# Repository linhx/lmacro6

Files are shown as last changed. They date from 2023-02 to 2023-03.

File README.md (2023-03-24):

# LMACRO6

My custom macropad

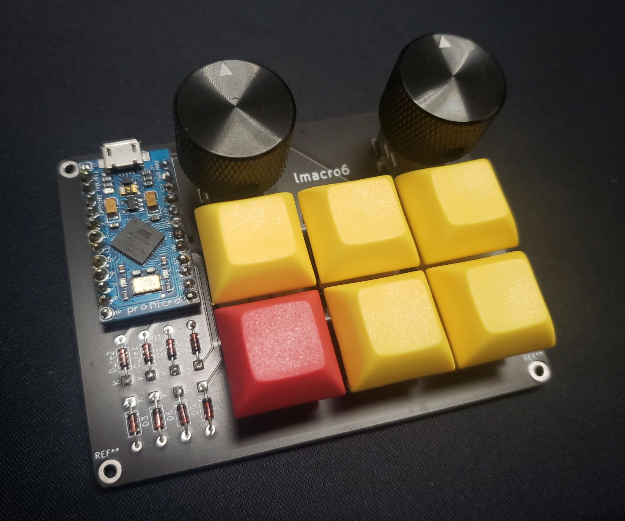
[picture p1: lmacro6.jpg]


## Default keymap

```plaintext
| F20            |            | Mute        |
| Ctrl + F12     | Alt + Left | Alt + Right |
| Ctrl + Alt + T |            |             |

* Left rotary encoder: Switch layer
* Right rotary encoder: Volume up/down

```

### useful macros (config via VIA)

* Open terminal in a directory (Nautilus Ubuntu): {KC_F10}{500}{KC_LALT,KC_E}

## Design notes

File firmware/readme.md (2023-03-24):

# lmacro6

A simple 6-keys macropad with two rotary encoders.

* Keyboard Maintainer: [Linhx](https://github.com/linhx)
* Hardware Supported: atmega32u4
* Hardware Availability: https://github.com/linhx/lmacro6

See the [build environment setup](https://docs.qmk.fm/#/getting_started_build_tools) and the [make instructions](https://docs.qmk.fm/#/getting_started_make_guide) for more information. Brand new to QMK? Start with our [Complete Newbs Guide](https://docs.qmk.fm/#/newbs).

## Default layout

```plaintext
| F20            |            | Mute        |
| Ctrl + F12     | Alt + Left | Alt + Right |
| Ctrl + Alt + T |            |             |

* Left rotary encoder: Switch layer
* Right rotary encoder: Volume up/down
```

### useful macros (config via VIA)

* Open terminal in a directory (Nautilus Ubuntu): {KC_F10}{500}{KC_LALT,KC_E}

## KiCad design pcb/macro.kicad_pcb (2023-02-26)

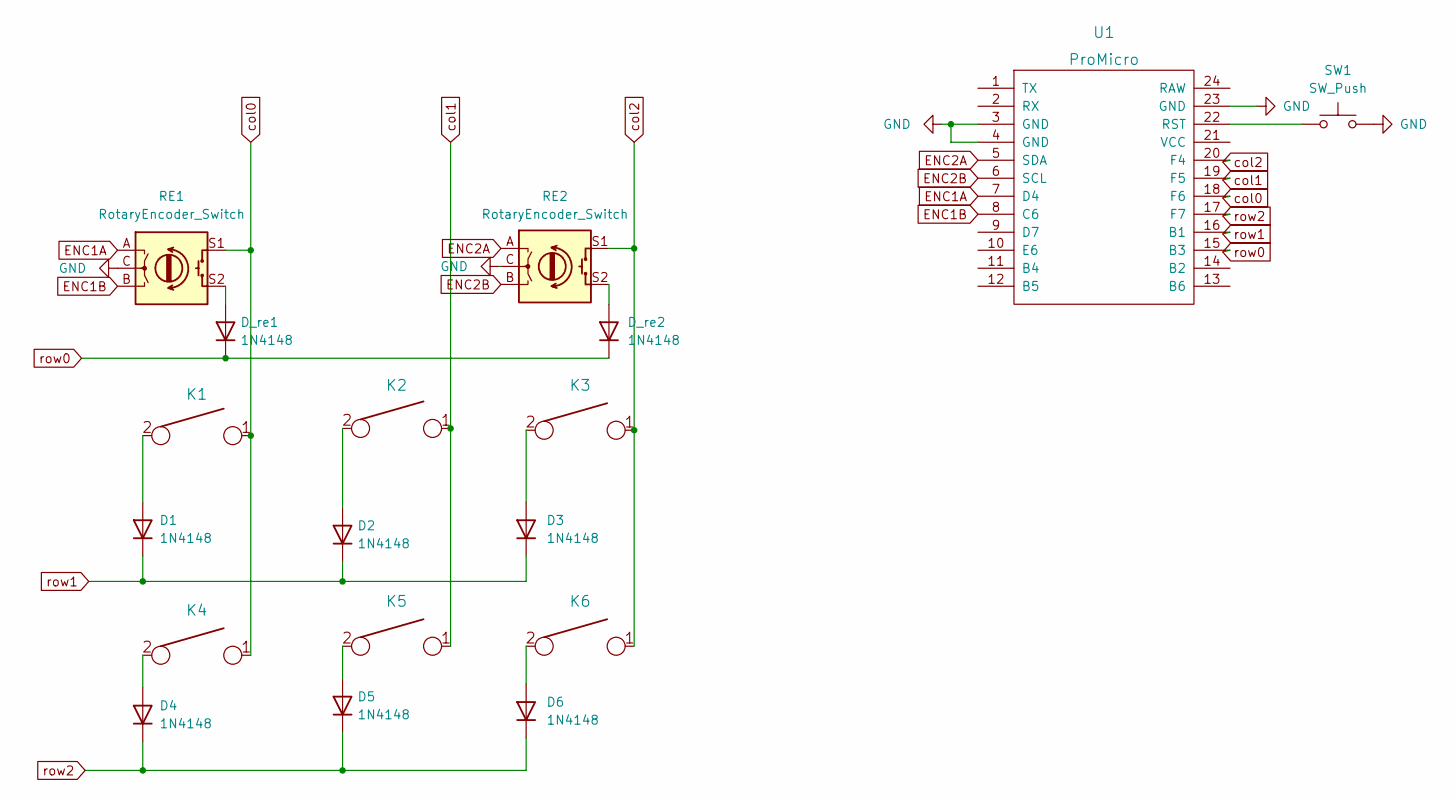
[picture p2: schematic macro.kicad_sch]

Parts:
D1, D2, D3, D4, D5, D6: 1N4148; D_DO-35_SOD27_P7.62mm_Horizontal
D_re1, D_re2: 1N4148; D_DO-35_SOD27_P7.62mm_Horizontal
K1, K2, K3, K4, K5, K6: KEYSW; SW_Cherry_MX_PCB_1.00u
RE1, RE2: RotaryEncoder_Switch; RotaryEncoder_Alps_EC11E-Switch_Vertical_H20mm
SW1: SW_Push; SW_SPST_CK_RS282G05A3
U1: ProMicro; Sparkfun_Pro_Micro

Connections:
ENC1A: RE1.A, U1.7 (D4)
ENC1B: RE1.B, U1.8 (C6)
ENC2A: RE2.A, U1.5 (SDA)
ENC2B: RE2.B, U1.6 (SCL)
GND: RE1.C, RE2.C, SW1.2, U1.3 (GND), U1.4 (GND), U1.23 (GND)
unnamed: D1.2 (A), K1.2
unnamed: D2.2 (A), K2.2
unnamed: D3.2 (A), K3.2
unnamed: D4.2 (A), K4.2
unnamed: D5.2 (A), K5.2
unnamed: D6.2 (A), K6.2
unnamed: D_re1.2 (A), RE1.S2
unnamed: D_re2.2 (A), RE2.S2
unnamed: SW1.1, U1.22 (RST)
col0: K1.1, K4.1, RE1.S1, U1.18 (F6)
col1: K2.1, K5.1, U1.19 (F5)
col2: K3.1, K6.1, RE2.S1, U1.20 (F4)
row0: D_re1.1 (K), D_re2.1 (K), U1.15 (B3)
row1: D1.1 (K), D2.1 (K), D3.1 (K), U1.16 (B1)
row2: D4.1 (K), D5.1 (K), D6.1 (K), U1.17 (F7)

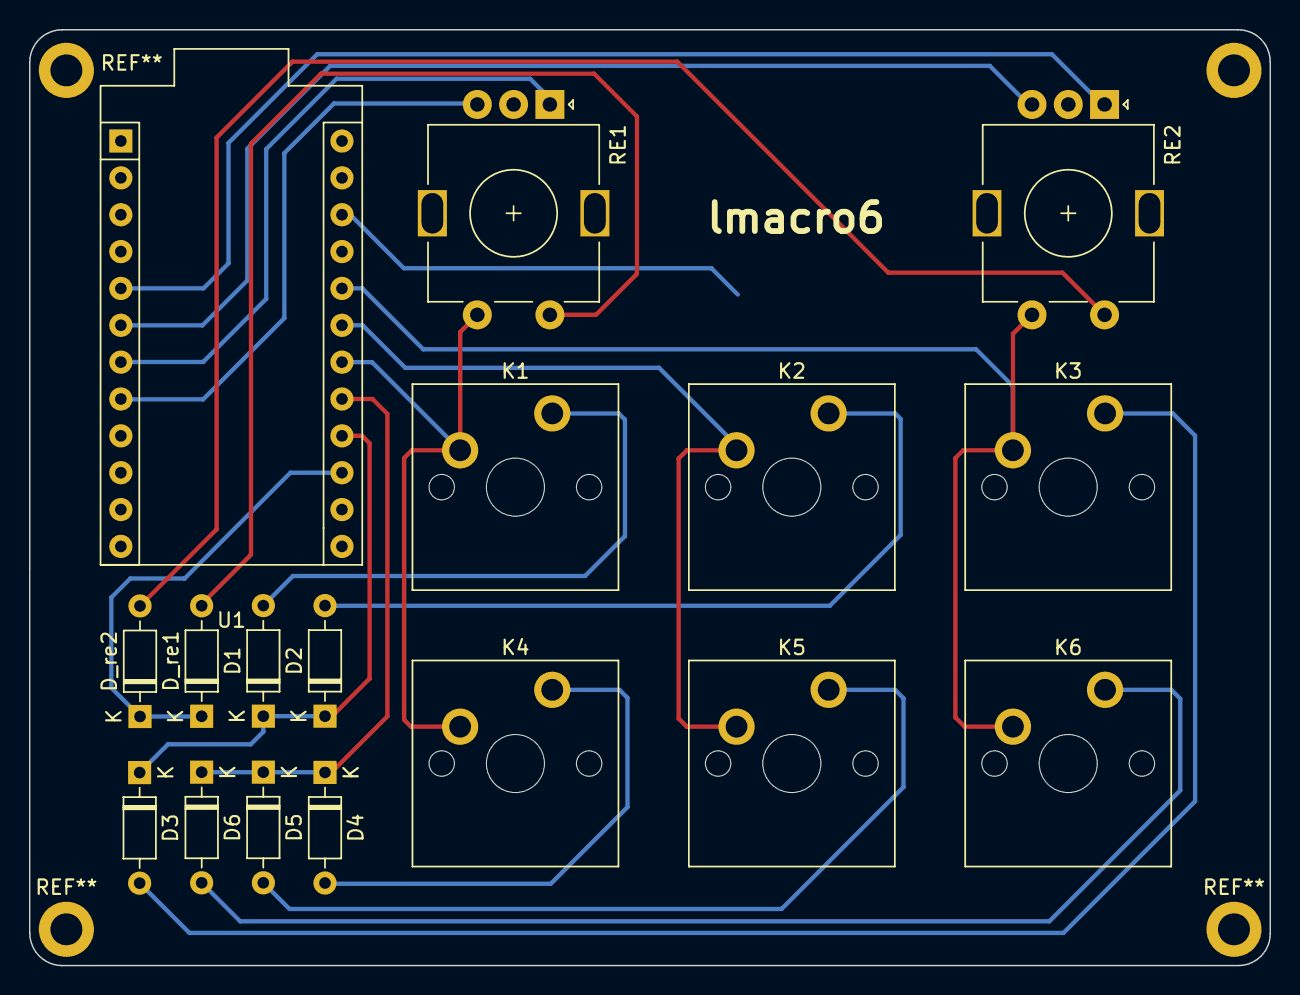
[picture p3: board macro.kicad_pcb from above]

Board: 2 copper layers, 85.5 x 64.5 mm, 18 parts (1 on the bottom side), 20 nets.

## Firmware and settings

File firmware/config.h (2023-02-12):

/*
Copyright 2023 Linhx

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
You should have received a copy of the GNU General Public License
along with this program.  If not, see <http://www.gnu.org/licenses/>.
*/

#pragma once

#include "config_common.h"

/* key matrix size */
#define MATRIX_ROWS 3
#define MATRIX_COLS 3

/*
 * Keyboard Matrix Assignments
 *
 * Change this to how you wired your keyboard
 * COLS: AVR pins used for columns, left to right
 * ROWS: AVR pins used for rows, top to bottom
 * DIODE_DIRECTION: COL2ROW = COL = Anode (+), ROW = Cathode (-, marked on diode)
 *                  ROW2COL = ROW = Anode (+), COL = Cathode (-, marked on diode)
 *
 */
#define MATRIX_ROW_PINS { B3, B1, F7 }
#define MATRIX_COL_PINS { F6, F5, F4 }

/* COL2ROW, ROW2COL */
#define DIODE_DIRECTION COL2ROW

/*
 * Split Keyboard specific options, make sure you have 'SPLIT_KEYBOARD = yes' in your rules.mk, and define SOFT_SERIAL_PIN.
 */
#define SOFT_SERIAL_PIN D0  // or D1, D2, D3, E6

//#define LED_NUM_LOCK_PIN B0
//#define LED_CAPS_LOCK_PIN B1
//#define LED_SCROLL_LOCK_PIN B2
//#define LED_COMPOSE_PIN B3
//#define LED_KANA_PIN B4

//#define BACKLIGHT_PIN B7
//#define BACKLIGHT_LEVELS 3
//#define BACKLIGHT_BREATHING

//#define RGB_DI_PIN E2
//#ifdef RGB_DI_PIN
//#    define RGBLED_NUM 16
//#    define RGBLIGHT_HUE_STEP 8
//#    define RGBLIGHT_SAT_STEP 8
//#    define RGBLIGHT_VAL_STEP 8
//#    define RGBLIGHT_LIMIT_VAL 255 /* The maximum brightness level */
//#    define RGBLIGHT_SLEEP  /* If defined, the RGB lighting will be switched off when the host goes to sleep */
/*== customize breathing effect ==*/
/*==== (DEFAULT) use fixed table instead of exp() and sin() ====*/
//#    define RGBLIGHT_BREATHE_TABLE_SIZE 256      // 256(default) or 128 or 64
/*==== use exp() and sin() ====*/
//#    define RGBLIGHT_EFFECT_BREATHE_CENTER 1.85  // 1 to 2.7
//#    define RGBLIGHT_EFFECT_BREATHE_MAX    255   // 0 to 255
//#endif

/* Debounce reduces chatter (unintended double-presses) - set 0 if debouncing is not needed */
#define DEBOUNCE 5

/* define if matrix has ghost (lacks anti-ghosting diodes) */
//#define MATRIX_HAS_GHOST

/* Mechanical locking support. Use KC_LCAP, KC_LNUM or KC_LSCR instead in keymap */
// #define LOCKING_SUPPORT_ENABLE
/* Locking resynchronize hack */
// #define LOCKING_RESYNC_ENABLE

/* If defined, GRAVE_ESC will always act as ESC when CTRL is held.
 * This is useful for the Windows task manager shortcut (ctrl+shift+esc).
 */
//#define GRAVE_ESC_CTRL_OVERRIDE

/*
 * Force NKRO
 *
 * Force NKRO (nKey Rollover) to be enabled by default, regardless of the saved
 * state in the bootmagic EEPROM settings. (Note that NKRO must be enabled in the
 * makefile for this to work.)
 *
 * If forced on, NKRO can be disabled via magic key (default = LShift+RShift+N)
 * until the next keyboard reset.
 *
 * NKRO may prevent your keystrokes from being detected in the BIOS, but it is
 * fully operational during normal computer usage.
 *
 * For a less heavy-handed approach, enable NKRO via magic key (LShift+RShift+N)
 * or via bootmagic (hold SPACE+N while plugging in the keyboard). Once set by
 * bootmagic, NKRO mode will always be enabled until it is toggled again during a
 * power-up.
 *
 */
//#define FORCE_NKRO

/*
 * Feature disable options
 *  These options are also useful to firmware size reduction.
 */

/* disable debug print */
//#define NO_DEBUG

/* disable print */
//#define NO_PRINT

/* disable action features */
//#define NO_ACTION_LAYER
//#define NO_ACTION_TAPPING
#define NO_ACTION_ONESHOT

/* Bootmagic Lite key configuration */
#define BOOTMAGIC_LITE_ROW 2
#define BOOTMAGIC_LITE_COLUMN 0

#define ENCODERS_PAD_A { D4, D1 }
#define ENCODERS_PAD_B { C6, D0 }

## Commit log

2023-02-12 feat: add PCB design; add testing firmware (tested on ProMicro)
    [macro.kicad_pcb, macro.kicad_sch]
2023-02-12 generate Gerber file
    [macro.kicad_pcb]
2023-02-12 feat: update clearance to 0.5mm
    [macro.kicad_pcb]
2023-02-13 feat: add button switch for reset
    [macro.kicad_pcb, macro.kicad_sch]
2023-02-26 fix: align rotary encoders.
    [macro-B_Cu.gbr, macro-B_Mask.gbr, macro-B_Paste.gbr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]
2023-02-27 chore: generate plots
    [macro-B_Cu.gbr, macro-B_Mask.gbr, macro-B_Paste.gbr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]
2023-03-24 feat: add 2 more layers, use TX/RX led as Layer indicator

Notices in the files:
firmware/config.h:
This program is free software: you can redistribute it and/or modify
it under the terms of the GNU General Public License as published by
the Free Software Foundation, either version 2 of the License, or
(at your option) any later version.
